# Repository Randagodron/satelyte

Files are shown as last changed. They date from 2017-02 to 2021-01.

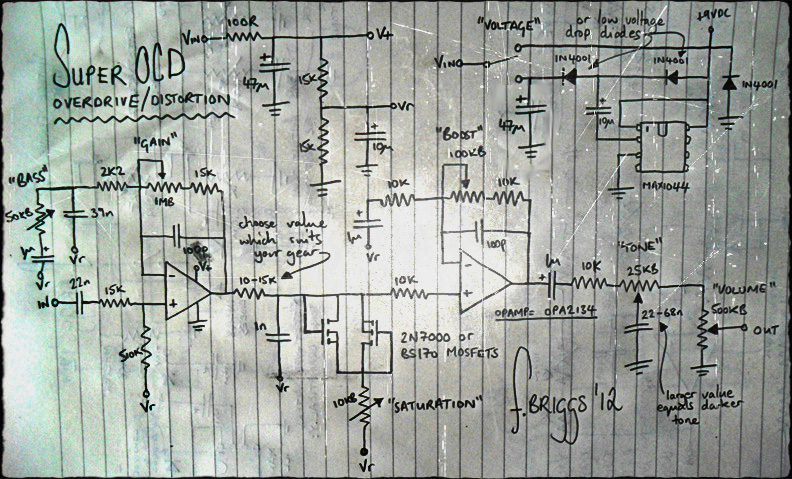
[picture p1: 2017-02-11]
doc/briggs_super_ocd.jpg

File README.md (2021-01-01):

# satelyte
Experimental distortion for electric guitar

Based on the Fulltone OCD and the Crowther Audio Prunes & Custard, with an additional octaver.

CAD done with KiCAD, simulation done with LTSpice.

Companion article (in french) : http://blog.randagodron.eu/index.php?post/2017/05/25/DIY-audio-Satelyte

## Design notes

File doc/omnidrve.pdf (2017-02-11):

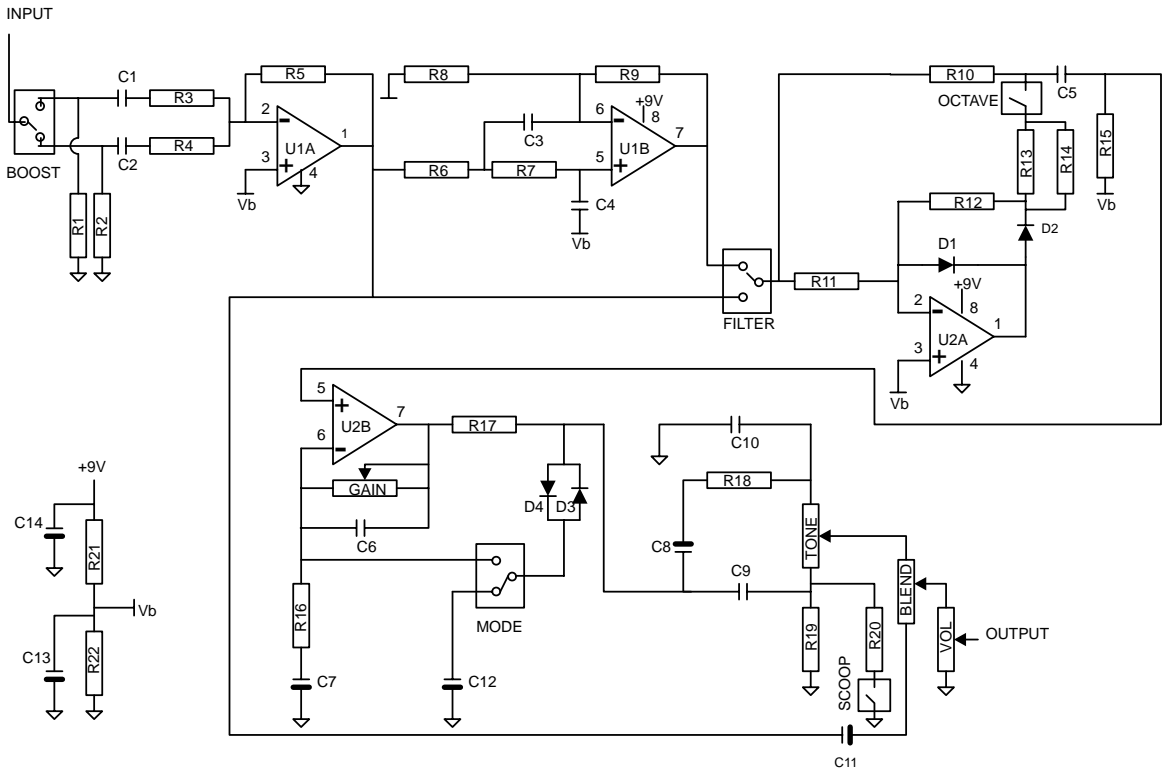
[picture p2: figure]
TONE; BLEND; VOL; GAIN; BOOST; FILTER; OCTAVE; MODE; SCOOP; OUTPUT; INPUT

R1 = 10M
R2 = 10M
R3 = 330K
R4 = 100K
R5 = 1M
R6 = 220K
R7 = 220K
R8 = 100K
R9 = 100K
R10 = 10K
R11 = 10K
R12 = 10K
R13 = 10K
R14 = 10K
R15 = 100K
R16 = 1K
R17 = 1K
R18 = 3.9K (3K9)
R19 = 10K
R20 = 1K
R21 = 10K
R22 = 10K

C1 = 0.01uF (10nF)
C2 = 0.001uF (1nF)
C3 = 0.001uF (1nF)
C4 = 0.001uF (1nF)
C5 = 0.01uF (10nF)
C6 = 47pF
C7 = 10uF
C8 = 1uF
C9 = 0.047uF (47nF)
C10 = 0.1uF (100nF)
C11 = 1uF
C12 = 10uF
C13 = 10uF
C14 = 10uF
U1, U2 = TL072
D1,2,3,4 = 1N914
GAIN = 470K pot
TONE = 10K Lin pot
BLEND = 47K Log pot
VOLUME = 100K Log

Miscellaneous:

SPDT switches for BOOST, FILTER, OCTAVE, MODE, SCOOP.

Use DPDT stomp switches if you want to add LED indicators for the various modes, tying an LED and 4.7K (4K7) resistor from +9V to ground through the extra switch section when the switch is in the indicator position. Bicolor LEDs work for adding two-position switches for BOOST and MODE.

DPDT stomp switch for bypass. Use Millenium Bypass for LED indicator and true bypass with only a DPDT.

You'll also need: Box (Hammond 1590BB works), battery clip, knobs for the pots, stereo 1/4" input jack, mono 1/4" output jack, hookup wire, and so on - the standard "wrapper" that goes on every effect.

*Layout updated 10/21/01; missing trace connecting R2 pad to ground.

# Omni Drive

as designed by John Hollis

Copyright 2001 R.G. Keen. All rights reserved. No permission for local copies or presentation from web sites other than http://www.geofex.com.

# Omni Drive

## PCB Layout and Wiring

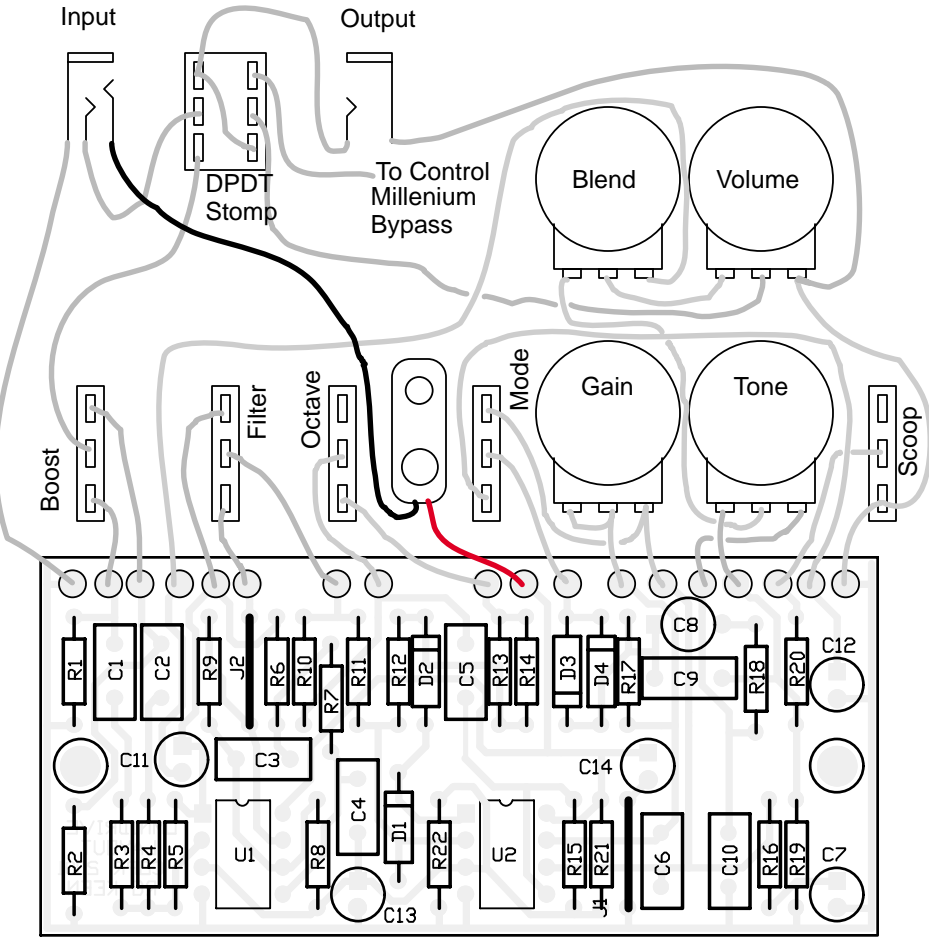
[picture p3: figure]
Boost; Filter; Octave; Mode; Scoop; Gain; Tone; Blend; Volume; Input; Output; To Control Millenium Bypass; DPDT Stomp
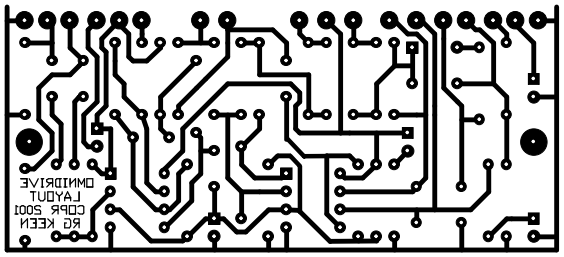
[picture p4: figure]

Copyright 2001 R.G. Keen. All rights reserved. No permission for local copies or presentation from web sites other than http://www.geofex.com.

Board is sized to fit inside a Hammond 1590BB, but with five toggle switches and four controls, it's going to be a very tight fit. I recommend the Hammond 1590DD, which has a much larger face, suitable for more controls.

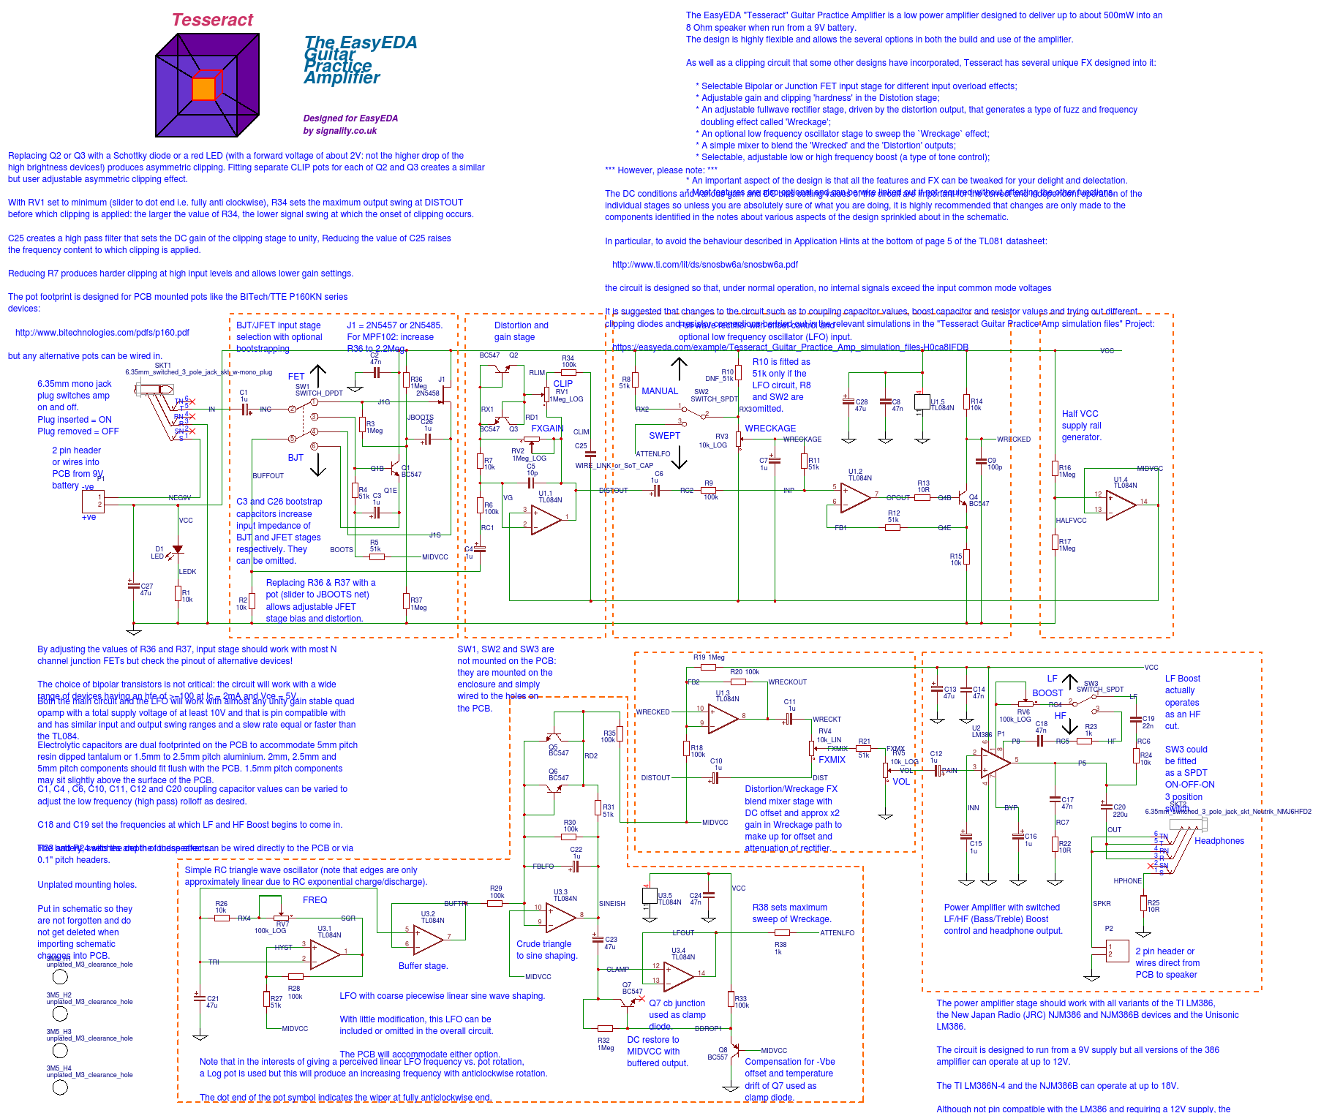
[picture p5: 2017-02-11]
doc/Tesseract_Guitar_Practice_Amp_Schematic-qoiASa4mE.png

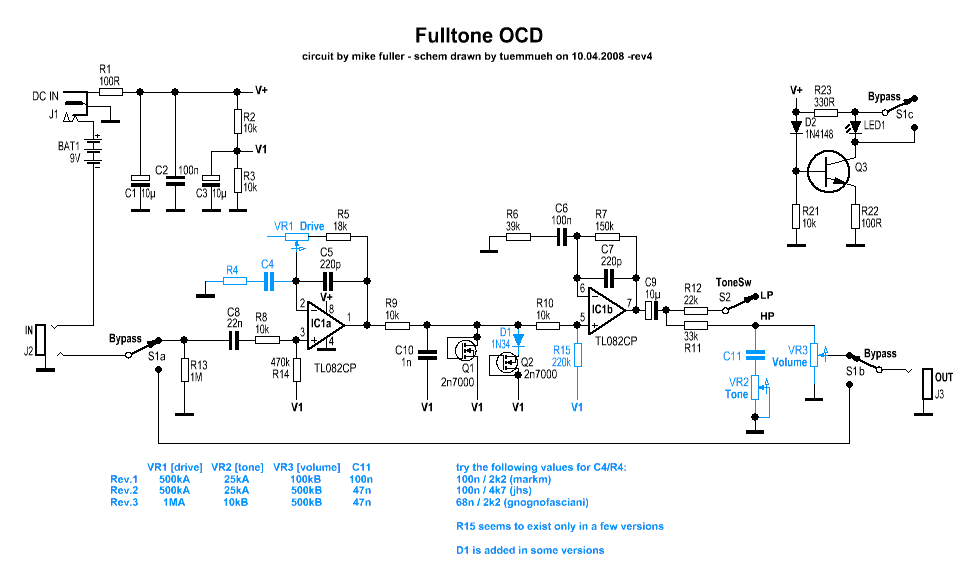
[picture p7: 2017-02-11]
doc/fulltone OCD.gif

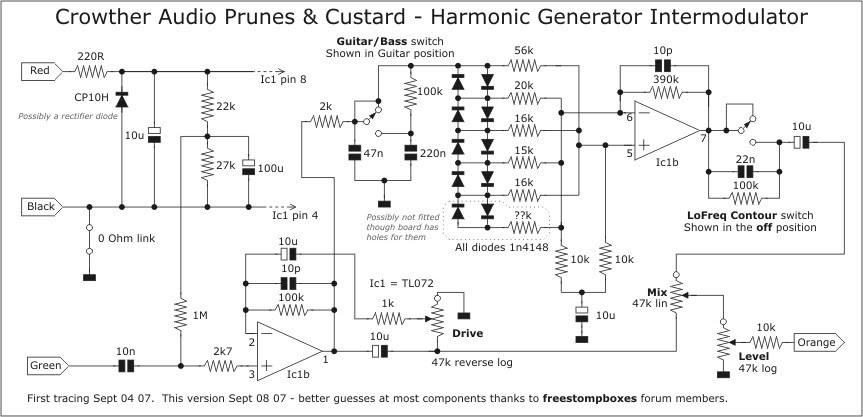
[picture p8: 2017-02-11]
doc/prunes_and_custard.jpg

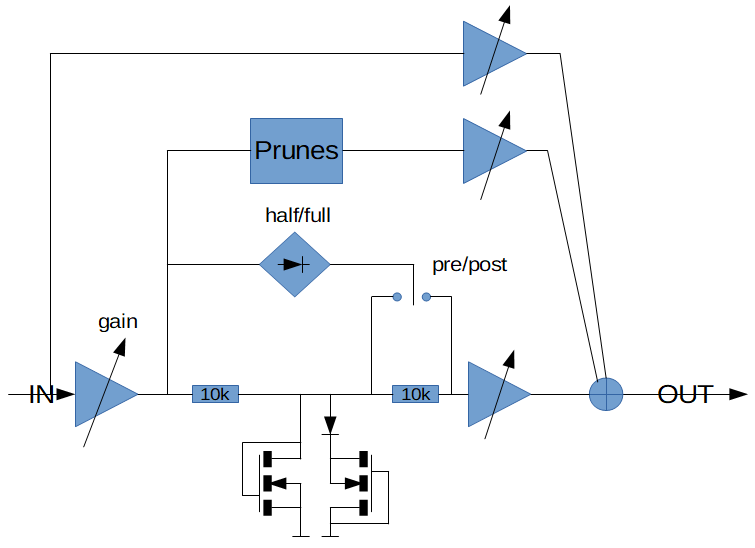
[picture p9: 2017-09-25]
export/topology.png

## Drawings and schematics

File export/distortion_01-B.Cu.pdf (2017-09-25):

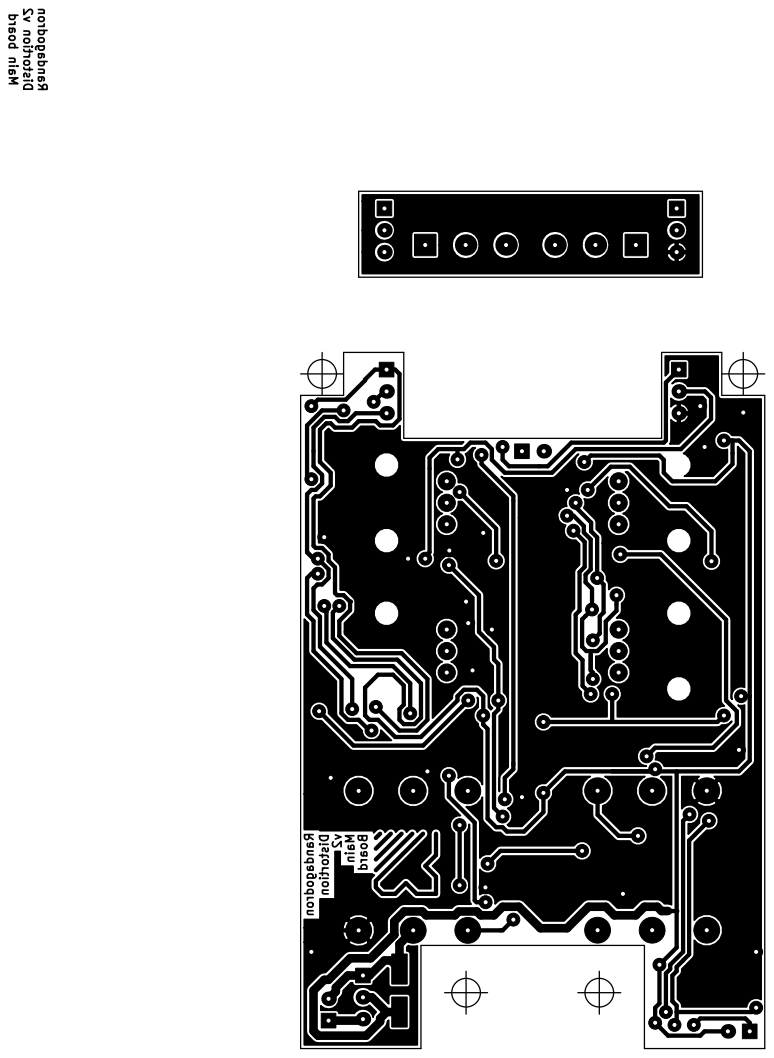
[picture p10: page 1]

Randagodron Distortion v2Main Board Distortion v2 Randagodron Main board

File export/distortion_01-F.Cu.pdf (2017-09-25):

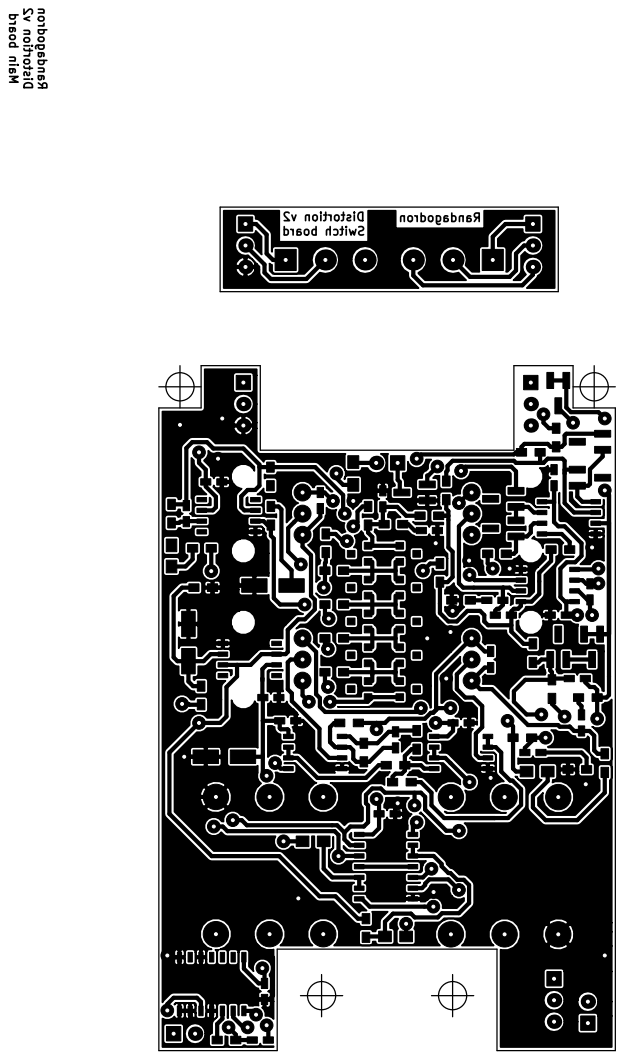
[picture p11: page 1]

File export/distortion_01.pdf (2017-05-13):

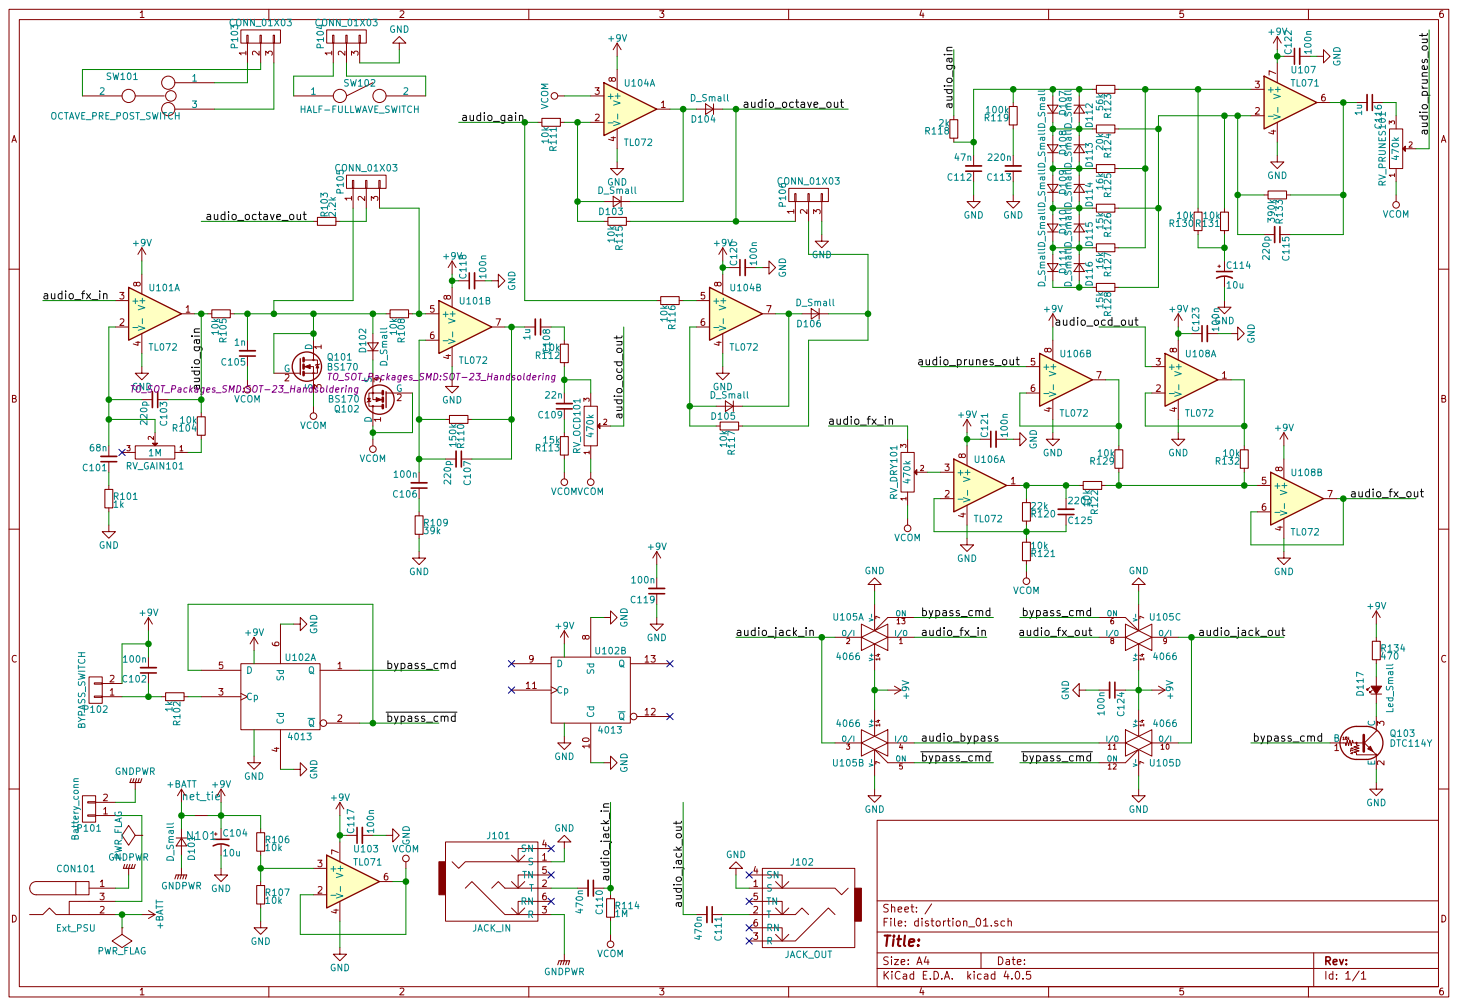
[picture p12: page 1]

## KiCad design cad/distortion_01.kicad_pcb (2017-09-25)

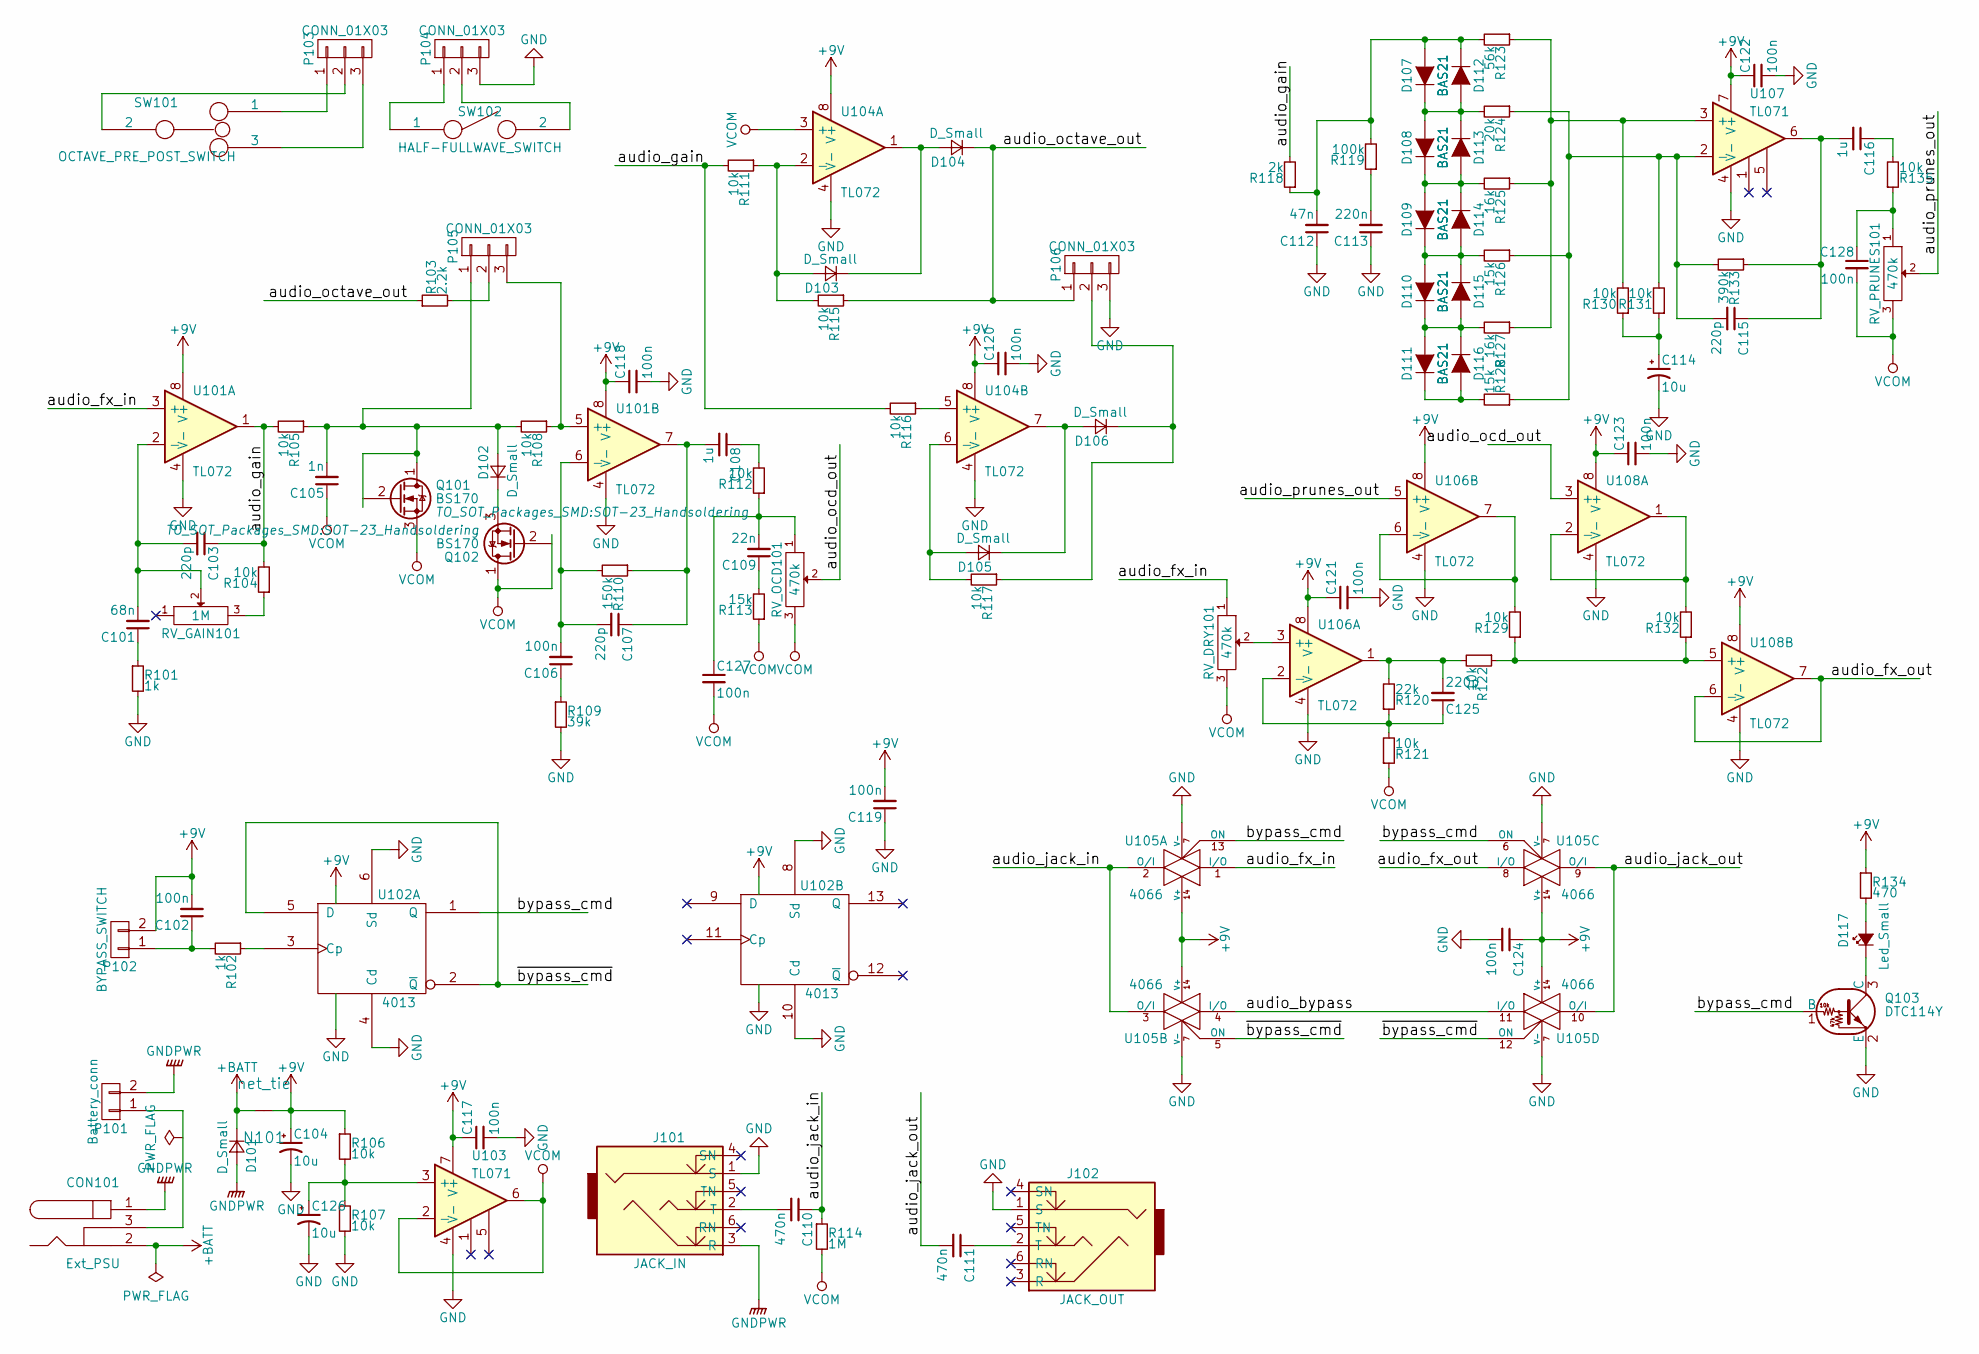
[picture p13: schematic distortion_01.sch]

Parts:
C101: 68n; C_0603_HandSoldering
C102, C106, C117, C118, C119, C120, C121, C122, C123, C124, C127, C128: 100n; C_0603_HandSoldering
C103, C107, C115, C125: 220p; C_0603_HandSoldering
C104, C114, C126: 10u; CP_Elec_5x4.5
C105: 1n; C_0603_HandSoldering
C108, C116: 1u; C_0805_HandSoldering
C109: 22n; C_0603_HandSoldering
C110, C111: 470n; C_0805_HandSoldering
C112: 47n; C_0603_HandSoldering
C113: 220n; C_0603_HandSoldering
CON101: Ext_PSU; Pin_Header_Straight_1x03_Pitch2.54mm
D101: D_Small; D_SMA_Handsoldering
D102, D103, D104, D105, D106: D_Small; SOT-23_Handsoldering
D107, D108, D109, D110, D111, D112, D113, D114, D115, D116: BAS21; SOT-23
D117: Led_Small; Pin_Header_Straight_1x02_Pitch2.54mm
J101: JACK_IN; NMJ6HCD2
J102: JACK_OUT; NMJ6HCD2
N101: net_tie; net_tie_0.5mm
P101: Battery_conn; Pin_Header_Straight_1x02_Pitch2.54mm
P102: BYPASS_SWITCH; Pin_Header_Straight_1x02_Pitch2.54mm
P103, P104, P105, P106: CONN_01X03; Pin_Header_Straight_1x03_Pitch2.54mm
Q101, Q102: BS170; SOT-23_Handsoldering
Q103: DTC114Y; SOT-23_Handsoldering
R101, R102: 1k; R_0603_HandSoldering
R103: 2.2k; R_0603_HandSoldering
R104, R105, R106, R107, R108, R111, R112, R115, R116, R117, R121, R122, R129, R130, R131, R132, R135: 10k; R_0603_HandSoldering
R109: 39k; R_0603_HandSoldering
R110: 150k; R_0603_HandSoldering
R113, R126, R128: 15k; R_0603_HandSoldering
R114: 1M; R_0603_HandSoldering
R118: 2k; R_0603_HandSoldering
R119: 100k; R_0603_HandSoldering
R120: 22k; R_0603_HandSoldering
R123: 56k; R_0603_HandSoldering
R124: 20k; R_0603_HandSoldering
R125, R127: 16k; R_0603_HandSoldering
R133: 390k; R_0603_HandSoldering
R134: 470; R_0805_HandSoldering
RV_DRY101: 470k; PTV09
RV_GAIN101: 1M; PTV09
RV_OCD101: 470k; PTV09
RV_PRUNES101: 470k; PTV09
SW101: OCTAVE_PRE_POST_SWITCH; SW_SPDT_through_hole
SW102: HALF-FULLWAVE_SWITCH; SW_SPDT_through_hole
U101, U104, U106, U108: TL072; SOIC-8-N
U102: 4013; SOIC-14_N
U103, U107: TL071; SOIC-8-N
U105: 4066; SOIC-14_N

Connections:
+9V: C102.2, C104.1, C117.1, C118.1, C119.2, C120.1, C121.1, C122.1, C123.1, C124.1, N101.2, P102.2, R106.1, R134.1, U101.8 (V+), U102.14 (VDD), U103.7 (V+), U104.8 (V+), U105.14 (V+), U106.8 (V+), U107.7 (V+), U108.8 (V+)
+BATT: CON101.2, D101.1 (K), N101.1
/audio_bypass: U105.4 (I/O), U105.11 (I/O)
/audio_fx_in: RV_DRY101.1, U101.3 (+), U105.1 (I/O)
/audio_fx_out: U105.8 (I/O), U108.6 (-), U108.7
/audio_gain: C103.1, R104.2, R105.2, R111.2, R116.2, R118.2, U101.1
/audio_jack_in: C110.1, R114.1, U105.2 (O/I), U105.3 (O/I)
/audio_jack_out: C111.2, U105.9 (O/I), U105.10 (O/I)
/audio_ocd_out: RV_OCD101.2, U108.3 (+)
/audio_octave_out: D104.1 (K), P106.1, R103.1, R115.1
/audio_prunes_out: RV_PRUNES101.2, U106.5 (+)
/bypass_cmd: Q103.1 (B), U102.1 (Q), U105.6 (ON), U105.13 (ON)
/~bypass_cmd~: U102.2 (~Q), U102.5 (D), U105.5 (ON), U105.12 (ON)
GND: C104.2, C112.1, C113.1, C114.2, C117.2, C118.2, C119.1, C120.2, C121.2, C122.2, C123.2, C124.2, C126.2, J101.1 (S), J102.1 (S), P104.3, P106.3, Q103.2 (E), R101.2, R107.2, R109.2, U101.4 (V-), U102.4 (Cd), U102.6 (Sd), U102.7 (VSS), U102.8 (Sd), U102.10 (Cd), U103.4 (V-), U104.4 (V-), U105.7 (V-), U106.4 (V-), U107.4 (V-), U108.4 (V-)
GNDPWR: CON101.1, D101.2 (A), J101.3 (R), P101.2
unnamed: C101.1, R101.1
unnamed: C101.2, C103.2, RV_GAIN101.2, U101.2 (-)
unnamed: C102.1, P102.1, R102.2
unnamed: C105.2, D102.2 (A), P105.1, Q101.1 (D), R105.1, R108.2
unnamed: C106.1, R109.1
unnamed: C106.2, C107.2, R110.2, U101.6 (-)
unnamed: C107.1, C108.2, R110.1, U101.7
unnamed: C108.1, R112.2
unnamed: C109.1, R113.2
unnamed: C109.2, C127.1, R112.1, RV_OCD101.1
unnamed: C110.2, J101.2 (T)
unnamed: C111.1, J102.2 (T)
unnamed: C112.2, D107.1 (A), D112.3 (K), R118.1, R119.2, R123.2
unnamed: C113.2, R119.1
unnamed: C114.1, R130.1, R131.1
unnamed: C115.1, C116.2, R133.1, U107.6
unnamed: C115.2, R124.1, R126.1, R128.1, R131.2, R133.2, U107.2 (-)
unnamed: C116.1, R135.2
unnamed: C125.1, R120.1, R121.2, U106.2 (-)
unnamed: C125.2, R120.2, R122.2, U106.1
unnamed: C126.1, R106.2, R107.1, U103.3 (+)
unnamed: C128.1, R135.1, RV_PRUNES101.1
unnamed: CON101.3, P101.1
unnamed: D102.1 (K), Q102.3 (S)
unnamed: D103.1 (K), D104.2 (A), U104.1
unnamed: D103.2 (A), R111.1, R115.2, U104.2 (-)
unnamed: D105.1 (K), D106.2 (A), U104.7
unnamed: D105.2 (A), R117.2, U104.6 (-)
unnamed: D106.1 (K), P106.2, R117.1
unnamed: D107.3 (K), D108.1 (A), D112.1 (A), D113.3 (K), R124.2
unnamed: D108.3 (K), D109.1 (A), D113.1 (A), D114.3 (K), R125.2
unnamed: D109.3 (K), D110.1 (A), D114.1 (A), D115.3 (K), R126.2
unnamed: D110.3 (K), D111.1 (A), D115.1 (A), D116.3 (K), R127.2
unnamed: D111.3 (K), D116.1 (A), R128.2
unnamed: D117.1 (K), Q103.3 (C)
unnamed: D117.2 (A), R134.2
unnamed: P103.1, SW101.1
unnamed: P103.2, SW101.2
unnamed: P103.3, SW101.3
unnamed: P104.1, SW102.1
unnamed: P104.2, SW102.2
unnamed: P105.2, R103.2
unnamed: P105.3, R108.1, U101.5 (+)
unnamed: R102.1, U102.3 (Cp)
unnamed: R104.1, RV_GAIN101.3
unnamed: R116.1, U104.5 (+)
unnamed: R122.1, R129.1, R132.1, U108.5 (+)
unnamed: R123.1, R125.1, R127.1, R130.2, U107.3 (+)
unnamed: R129.2, U106.6 (-), U106.7
unnamed: R132.2, U108.1, U108.2 (-)
unnamed: RV_DRY101.2, U106.3 (+)
VCOM: C105.1, C127.2, C128.2, Q101.3 (S), Q102.1 (D), R113.1, R114.2, R121.1, RV_DRY101.3, RV_OCD101.3, RV_PRUNES101.3, U103.2 (-), U103.6, U104.3 (+)

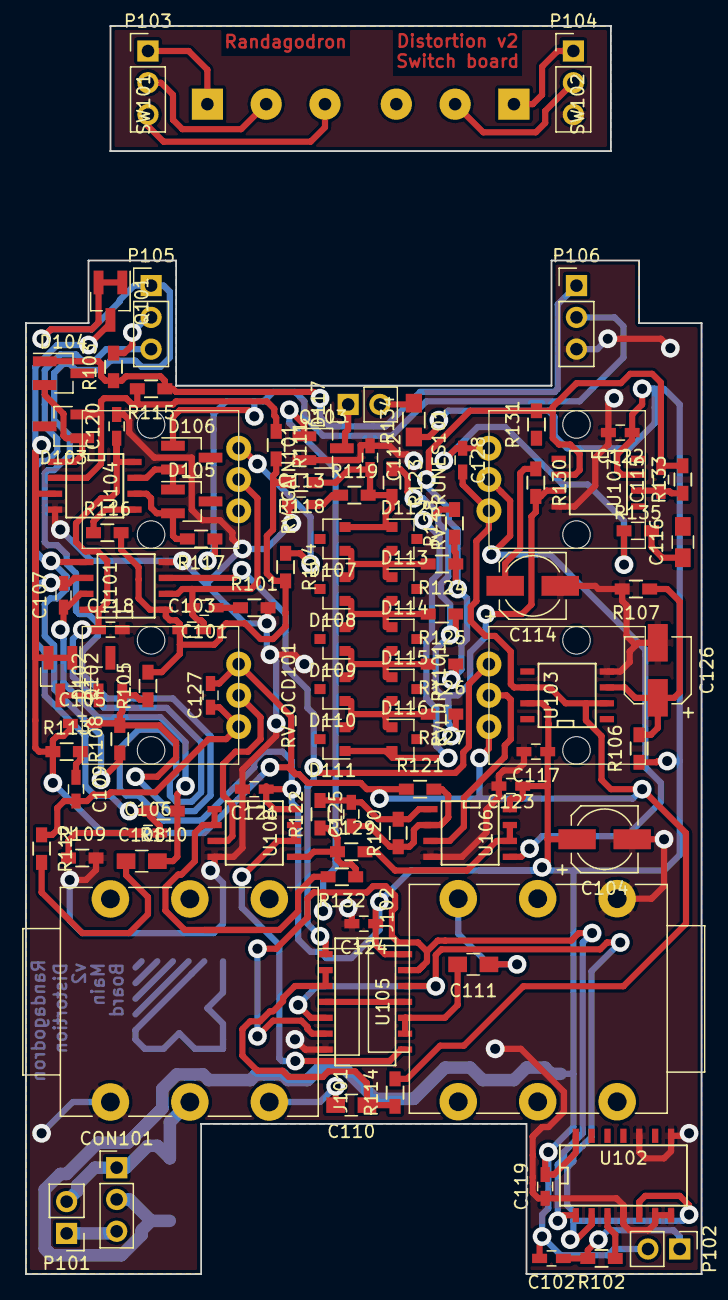
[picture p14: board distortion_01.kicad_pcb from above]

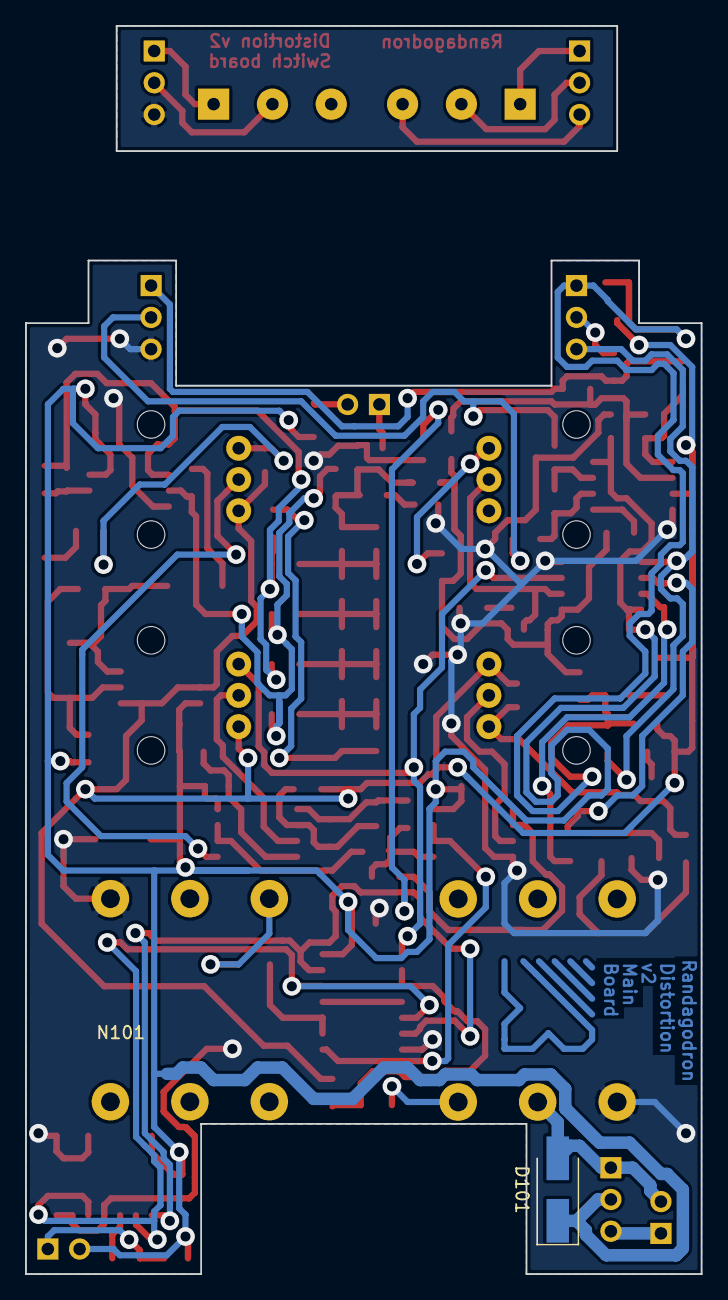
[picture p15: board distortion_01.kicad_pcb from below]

Board: 2 copper layers, 54.0 x 81.0 mm, 107 parts (2 on the bottom side), 67 nets.

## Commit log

2017-02-11 Schematic done, to be simulated.
    [distortion_01.kicad_pcb, distortion_01.sch]
2017-02-11 Added octave.
    [distortion_01.sch]
2017-02-12 Simulated OCD / octave part.
    [distortion_01.sch]
2017-02-12 Added gain for dry signal. Assigned footprints (TBC).
    [distortion_01.sch]
2017-02-12 Added names on pots.
    [distortion_01.kicad_pcb, distortion_01.sch]
2017-02-13 Placement started with 1590B cutout. Too small, 1590BB required.
    [distortion_01.kicad_pcb, distortion_01.sch]
2017-02-15 Changed edge cuts to 1590BB. Made pre-placement.
    [distortion_01.kicad_pcb, distortion_01.sch]
2017-02-25 Finished layout.
    Added switch board.
    [distortion_01.kicad_pcb, distortion_01.sch]
2017-02-25 Minor corrections.
    [distortion_01.kicad_pcb, distortion_01.sch]
2017-02-25 Started placement. Output OPA TL074 changed to 2x TL072.
    [distortion_01.kicad_pcb, distortion_01.sch]
2017-03-04 Added 220p capa in feedback loop of dry OPA. Placed all components on PCB.
    [distortion_01.kicad_pcb, distortion_01.sch]
2017-03-04 Continued layout. Changed 4066 pinout.
    [distortion_01.kicad_pcb, distortion_01.sch]
2017-03-22 Finished layout.
    [distortion_01.kicad_pcb, distortion_01.sch]
2017-03-22 Corrected layout.
    [distortion_01.kicad_pcb]
2017-03-25 Corrected pots pinout and layout.
    [distortion_01.kicad_pcb, distortion_01.sch]
2017-03-25 Continued layout
    [distortion_01.kicad_pcb, distortion_01.sch]
2017-03-29 Finished layout
    [distortion_01.kicad_pcb]
2017-04-01 Corrected layout. Added board name.
    [distortion_01.kicad_pcb]
2017-05-11 Corrected connectors placement, switch IC and PSU connectors should be swapped for easier routing.
    [distortion_01.kicad_pcb]
2017-05-13 Changed PSU connector footprint to 3w HE10, finished layout.
    [distortion_01.kicad_pcb, distortion_01.sch]
2017-05-13 Minor corrections on layout. Added logo.
    [distortion_01.kicad_pcb]
2017-05-25 Exported layout and drill plan.
2017-09-04 Added LTspice simulation.
    Added 10n cap on OCD output.
    Added 10u cap on Vref for HF stability.
    [distortion_01.kicad_pcb, distortion_01.sch]
2017-09-04 Updated PCB number to v2.
    [distortion_01.kicad_pcb]
2017-09-05 Corrected pots polarity (schematic and layout).
    [distortion_01.kicad_pcb, distortion_01.sch]
2017-09-13 Added schematics screenshots.
    Changed diodes symbols to BAS21.
    [distortion_01.sch]
2017-09-25 Added output capacitor on Prunes.
    Changed capacitor value on octave output.
    Corrected layout accordingly.
    [distortion_01.kicad_pcb, distortion_01.sch]
2017-09-25 Exported schematic, added topology drawing.
